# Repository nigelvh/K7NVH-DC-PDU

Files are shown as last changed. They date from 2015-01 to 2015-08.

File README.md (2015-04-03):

K7NVH DC PDU
=======

The K7NVH DC PDU is a device designed to provide remote power control of DC devices in an affordable, low power, and flexible package. Each port is rated to handle 3 amps, and can also measure the current and power flowing through each port.

A variety of features are available, including user defined overcurrent protection, automatic port control based on voltage thresholds, human readable and parseable status displays, port cycling with user defined delay, user defined port state on PDU startup, user defined names for each port and the PDU itself, and options for calibrating the voltage and current sense functions.

Power can be supplied to the device via either USB or a standard barrel jack at 5V, and the device draws approximately 20mA. Please ensure that you supply ONLY regulated 5V. Supplying more than 5V will damage the PDU. You can choose how the device is powered (USB or Barrel Jack) via the solder jumper on the bottom of the board.

The device is available to the host system as a USB serial device, which when accessed accepts a number of basic ASCII commands which can be entered manually, or via a user created script to automate control actions.

This repository contains the source code to be compiled with AVR-GCC, and uploaded to the device via ATMEL's FLIP programmer. There are also resources like CAD files for a case for the device, as well as example resources for configuring a PDU connected computer for providing PDU status data via SNMP.

## Supported Commands
### HELP
The 'HELP' command will print a short message referencing the project page containing documentation.

### STATUS
The 'STATUS' command is designed to give an overview of the running state of each port on the PDU. The port numbers, any configured custom port names, and port state (ENABLED/DISABLED) will be displayed. Input voltage, board temperature, and per port current and power values will be shown. Voltages sensed on the auxiliary inputs will also be displayed. Note that unconnected auxiliary inputs may float and show voltages on unconnected pins. Messages that ports have been disabled due to overload, or are under automatic voltage control are displayed if applicable.

```plain
> STATUS
Voltage: 13.76V Temperature: 25C
PORT 1 "": ENABLED Current: 0.00A Power: 0.0W 
PORT 2 "": ENABLED Current: 0.00A Power: 0.0W 
PORT 3 "": ENABLED Current: 0.00A Power: 0.0W 
PORT 4 "": ENABLED Current: 0.00A Power: 0.0W 
PORT 5 "": ENABLED Current: 0.00A Power: 0.0W 
PORT 6 "": ENABLED Current: 0.00A Power: 0.0W 
PORT 7 "": ENABLED Current: 0.00A Power: 0.0W 
PORT 8 "": ENABLED Current: 0.00A Power: 0.0W 
AUX 1:0.01V 2:0.04V 3:0.01V 4:0.02V 5:0.03V 6:0.00V
```

### PSTATUS
The 'PSTATUS' command is designed to give an overview of the running state of the PDU in a easily parseable format for use with programs querying the PDU for information. The output is in a simple CSV format, defined as follows.

```plain
K7NVH DC PDU,Version Number,Device Name
Input Voltage,Board Temperature
AIN1,AIN2,AIN3,AIN4,AIN5,AIN6
Port Number,Port Name,Binary Enabled/Disabled Flag,Port Current,Port Power,Binary Overload Flag,Automatic Voltage Control Flag
(The above line is repeated for each port)
```
An example output might look like the following.
```plain
> PSTATUS
K7NVH DC PDU,1.1,
2.15,23
0.02,0.04,0.03,0.01,0.01,0.03
0,,1,0.00,0.0,0,0
1,,1,0.00,0.0,0,0
2,,1,0.00,0.0,0,0
3,,1,0.00,0.0,0,0
4,,1,0.00,0.0,0,0
5,,1,0.00,0.0,0,0
6,,1,0.00,0.0,0,0
7,Port 8,1,0.03,0.1,0,0
```

### PON
The 'PON' command is used to enable one or more ports on the PDU.

The PDU supports enabling multiple ports at a time. For example, all of the following are valid 'PON' syntaxes. 'A' can also be substituted for a port number to enable all ports.
`PON 1` `PON 1 2 3 4` `PON A`

### POFF
The 'POFF' command is used to disable one or more ports on the PDU.

The PDU supports disabling multiple ports at a time. For example, all of the following are valid 'POFF' syntaxes. 'A' can also be substituted for a port number to disable all ports.
`POFF 1` `POFF 1 2 3 4` `POFF A`

### PCYCLE
The 'PCYCLE' command is used to disable one or more ports on the PDU for a period of time set by the 'SETCYCLE' command, after which, the port is enabled again.

If 'PCYCLE' is issued on a port that is already disabled, the port will remain disabled for the period of time set by the 'SETCYCLE' command, and will be enabled with any other ports specified.

The PDU supports cycling multiple ports at a time. 'A' can also be substituted for a port number to cycle all ports. The following are valid PCYCLE syntaxes. `PCYCLE 1` `PCYCLE 1 2 3 4` `PCYCLE A`

### SETCYCLE
The 'SETCYCLE' command is used to set the period of time in seconds that ports will be disabled on the PDU during a 'PCYCLE' command. This command has no immediate impact on any ports.

Valid range for the 'SETCYCLE' command is 0-30 seconds. 0 seconds being no delay between disabling and re-enabling a port, and 30 seconds being the maximum delay allowable.

For example, to set a 5 second delay, the following is valid 'SETCYCLE' syntax. `SETCYCLE 5`

### SETDEFON
The 'SETDEFON' command is used to store the desired default state of a given port at PDU boot time to enabled. The PDU will default to all ports being enabled at boot, but you may leave ports disabled at boot with the 'SETDEFOFF' command, or set them back to enabled via 'SETDEFON'.

The PDU supports setting multiple ports at a time to be enabled by default. 'A' can also be substituted for a port number to change all ports. `SETDEFON 1` `SETDEFON 1 2 3 4` `SETDEFON A`

### SETDEFOFF
The 'SETDEFOFF' command is used to store the desired default state of a given port at PDU boot time to disabled. The PDU will default to all ports being enabled at boot, but you may leave ports disabled at boot with the 'SETDEFOFF' command, or set them back to enabled via 'SETDEFON'.

The PDU supports setting multiple ports at a time to be disabled by default. 'A' can also be substituted for a port number to change all ports. `SETDEFOFF 1` `SETDEFOFF 1 2 3 4` `SETDEFOFF A`

### SETNAME
The 'SETNAME' command is used to store a user defined "helpful" name for each port on the PDU. By default the custom names are blank, but they may be set to a user defined string of up to 15 characters in length. Strings longer than 15 characters will be truncated.

The user defined name will be displayed alongside the port number in the output from the 'STATUS' command.

The PDU supports setting only one port name at a time. The following is an example of valid 'SETNAME' syntax, setting Port 1's name to "Testing". `SETNAME 1 Testing`

The 'SETNAME' command can also be used to give the PDU device an overall name by using 'P' in place of the port number. The device name will be displayed as part of the input prompt as a visual aid to ensure users are interacting with the intended device. The following is an example of valid 'SETNAME' syntax to set the device name. `SETNAME P PDU-Test`

The same string length limits that apply to individual port names also apply to the device name.

### SETLIMIT
The 'SETLIMIT' command is used to store a user defined overload current limit for each port on the PDU. By default the current limit is set to 10 amps. While the PDU is not rated for this current flow, 10A was chosen to effectively "disable" current limits from disabling PDU ports.

During normal operation the PDU will continuously check current flow on each port, and compare against the stored limits. If a port is found to exceed the stored limit for greater than 10ms (milliseconds), the port will be disabled, a warning message will be printed, and a overload flag will be displayed in the 'STATUS' output.

If a port has been disabled due to current overload, the port can be re-enabled with a manual 'PON' command.

'SETLIMIT' is set in units of mA (milliamps), and accepts values from 0 to 10000 (0 to 10 amps). However, the provided input will be truncated to tenths of amps. For example, a value of 1150, will be truncated to 1.1A.

The PDU supports setting only one port limit at a time. The following is an example of setting Port 1's current limit to 1.5A. `SETLIMIT 1 1500`

### VCTLON
The 'VCTLON' command is used to enable the PDU to control a given port automatically based on the sensed input voltage. This setting is persistent across reboots of the PDU device. Automatic voltage control of a given port is disabled until manually enabled again, or the PDU is rebooted, in the case of any manual action controlling a port, or an overload condition disables a port.

The voltage thresholds for enabling and disabling a port are set with the 'SETVCTLON' and 'SETVCTLOFF' commands.

Input voltage is polled approximately every 5 seconds, and ports will be enabled/disabled after two consecutive polling cycles have shown voltages beyond the configured thresholds.

Automatic voltage control can be very helpful for battery powered environments, to disable devices if available battery power runs too low. As each port can have unique settings, the user can configure staggered shutdown or startup for equipment as batteries are drained, and subsequently recharged.

The PDU supports setting multiple ports at a time for automatic control. The following are examples of valid syntax for enabling automatic control. `VCTLON 1` `VCTLON 1 2 3 4`

### VCTLOFF
The 'VCTLOFF' command is used to disable the PDU from controlling a given port automatically based on the sensed input voltage. This setting is persistent across reboots of the PDU device.

The PDU supports setting multiple ports at a time for disabled automatic control. The following are examples of valid syntax for disabling automatic control. `VCTLOFF 1` `VCTLOFF 1 2 3 4`

### SETVCTLON
The 'SETVCTLON' command is used to set the voltage, at which a port should be enabled, when configured for automatic control. By default this value is set at 40 volts, the limit of the PDU device, effectively disabling automatic port control.

'SETVCTLON' is set in units of hundredths of volts, and accepts values from 0 to 4000 (0 to 40 volts).

The PDU supports setting only one port enable threshold at a time. The following is an example of setting the enable threshold of Port 1 to 10 volts. `SETVCTLON 1 1000`

### SETVCTLOFF
The 'SETVCTLOFF' command is used to set the voltage, at which a port should be disabled, when configured for automatic control. By default this value is set at 0 volts, effectively disabling automatic port control.

'SETVCTLOFF' is set in units of hundredths of volts, and accepts values from 0 to 4000 (0 to 40 volts).

The PDU supports setting only one port disable threshold at a time. The following is an example of setting the disable threshold of Port 1 to 10 volts. `SETVCTLON 1 1000`

### SETVREF
The 'SETVREF' command is used only during calibration of the PDU. Measuring the voltage reference regulator with an accurate voltage meter, the calibration of voltage and current measurements can be updated.

'SETVREF' is set in units of mV (millivolts), and accepts values from 4000 to 4400 (4.0V to 4.4V). The default value if uncalibrated is the regulator's nominal output voltage of 4.2V.

For example, to set the voltage reference calibration to 4.2V, the following are valid 'SETVREF' syntaxes. `SETVREF4200` `SETVREF 4200`

### SETVCAL
The 'SETVCAL' command is used only during calibration of the PDU. Measuring the voltage divider on the input port with an accurate voltage meter, calibration of voltage supply measurements can be made.

'SETVCAL' is a unitless multiplier, specified in VALUE*10, and accepts values from 150 to 70 (15.0X to 7.0X). The default value if uncalibrated is the dividers's nominal voltage division of 11.0X.

For example, to set the divider reference calibration to 11.0X, the following are valid 'SETVCAL' syntaxes. `SETVCAL110` `SETVCAL 110`

### SETICAL
The 'SETICAL' command is used only during calibration of the PDU. Measuring the voltage divider on the current sense op amp for a given port with an accurate meter, calibration of current sense measurements can be made.

'SETICAL' is a unitless multiplier, specified in VALUE*10, and accepts values from 160 to 60 (16.0X to 6.0X). The default value if uncalibrated is the dividers's nominal voltage division of 11.0X.

For example, to set the calibration on port 1 to 11.0X, the following is valid 'SETICAL' syntax. `SETICAL 1 110`

### DEBUG
The 'DEBUG' command is useful for debugging PDU state. It will output a variety of values, and may not be formatted for easy understanding.

In the cases of unset or default values, the 'DEBUG' command may return a number of unprintable characters to your terminal. This is expected behavior.

## Drivers
The PDU board is automatically recognized as a USB serial device under OSX and Linux, however, windows requires a driver to associate the device with the built in USB serial device drivers.

When first attaching the device to a windows based host, windows will attempt to find a driver and fail. You may then specify a driver. This is provided in K7NVH_PDU.inf.

Once you have installed the driver, the PDU will register as a COM port device under windows, and you may access it with any serial/terminal application of your preference.

### Windows 8 Users
During the driver installation process on Windows 8 operating systems you may encounter *"The third-party INF does not contain digital signature information"* preventing the installation of the included PDU driver.  The steps below outline the process for disabling driver signature enforcement on Windows 8/8.1 systems.

**NOTE:** If your system uses BitLocker Drive Encryption, you will need your encryption key to gain access to advanced settings to disable driver signature enforcement.

Windows 8 - Navigate to PC settings > General and look for the *Advanced startup* dialog.  Click the **Restart now** button to access the advanced startup settings.  Your system will now reboot.

Windows 8.1 - Navigate to PC settings > Update and Recovery > Recovery and look for the *Advanced startup* dialog.  Click the **Restart now** button to access the advanced startup settings.  Your system will now reboot.

After rebooting select Troubleshoot > Advanced options > Startup Settings, click the **Restart** button, your machine will reboot a second time.

After rebooting a second time you should be presented with the Windows Startup Settings dialog, choose *Disable driver signature enforcement* by pressing number `7` on your keyboard.  Your machine will reboot automatically.

Once rebooted, you should now be able to install the PDU drviers as outlined above.  Once the appropriate driver is selected you will see a Windows Security dialog warning against the installation of the unsigned driver.  Click **Install this driver software anyway** to complete the driver installation.

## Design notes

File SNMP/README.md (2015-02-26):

SNMP
=======

## k7nvh_dc_pdu.c
This is the C source for a program to interact with the PDU, and output the data to stdout. Invocation will be along the lines of `k7nvh_dc_pdu /dev/serialDeviceName 'STATUS'` to send the PDU the STATUS command, and print the output. To connect to the PDU, the user running the application must be a member of the 'dialout' group under linux. Under other systems, whatever permissions needed to interact with serial ports are required.

Note that this utility at present simply responds with all output received before a 1 second timeout. This should accomodate all functions except PCYCLE.

## pdu_snmp
This is a PHP script intended to be run on the command line (php-cli is required), and interprets the output from a STATUS command into SNMP OIDs. By default it will read this output from the `/tmp/pdu_status.txt` file. In my environment, this file is populated by an entry in the system crontab, that runs the `k7nvh_dc_pdu` utility. This crontab entry looks like: 
`* * * * *       root    /nigel_scripts/PDU/k7nvh_dc_pdu /dev/ttyACM1 'STATUS' |egrep -i "Voltage|PORT" > /tmp/pdu_status.txt`

Then your snmpd installation needs to be configured to pass the proper OID requests to the `pdu_snmp` script. In my `/etc/snmp/snmpd.conf` file, I have added the following config option:
`pass .1.3.6.1.4.1.8072.2.2048   "/nigel_scripts/PDU/pdu_snmp"`

Now, you should be able to snmpget or snmpwalk PDU data. For example, this will snmpwalk the current usage on each port.
```plain
snmpwalk -v 2c -c <COMMUNITY> <IP ADDRESS> .1.3.6.1.4.1.8072.2.2048.1.3.3
iso.3.6.1.4.1.8072.2.2048.1.3.3.1.1 = STRING: "0.00"
iso.3.6.1.4.1.8072.2.2048.1.3.3.2.1 = STRING: "0.00"
iso.3.6.1.4.1.8072.2.2048.1.3.3.3.1 = STRING: "0.00"
iso.3.6.1.4.1.8072.2.2048.1.3.3.4.1 = STRING: "0.00"
iso.3.6.1.4.1.8072.2.2048.1.3.3.5.1 = STRING: "0.17"
iso.3.6.1.4.1.8072.2.2048.1.3.3.6.1 = STRING: "0.22"
iso.3.6.1.4.1.8072.2.2048.1.3.3.7.1 = STRING: "0.00"
```

Other OIDs of interest that can be walked are:
```plain
.1.3.6.1.4.1.8072.2.2048.1.2.1.1.1 -> Input Voltage
.1.3.6.1.4.1.8072.2.2048.1.3.0 -> Port Index
.1.3.6.1.4.1.8072.2.2048.1.3.1 -> Port Names
.1.3.6.1.4.1.8072.2.2048.1.3.2 -> Port Status
.1.3.6.1.4.1.8072.2.2048.1.3.3 -> Port Current
.1.3.6.1.4.1.8072.2.2048.1.3.4 -> Port Power
```

Please note that SNMP is dumb (IMO) and when interacting with programs like Cacti that expect data to be formatted and organized in a certain way, when adding new data to the OID tree, I may have to reorganize, and thus I do not guarantee the OIDs will remain the same with any updates to this script. Sorry!

## Cacti
The Cacti folder contains some example configuration/templates for Cacti to use to create graphs based on the SNMP data available through the above scripts from the PDU. These work for me and have been exported from my working config, but may not work for you. Please take them as references/examples.

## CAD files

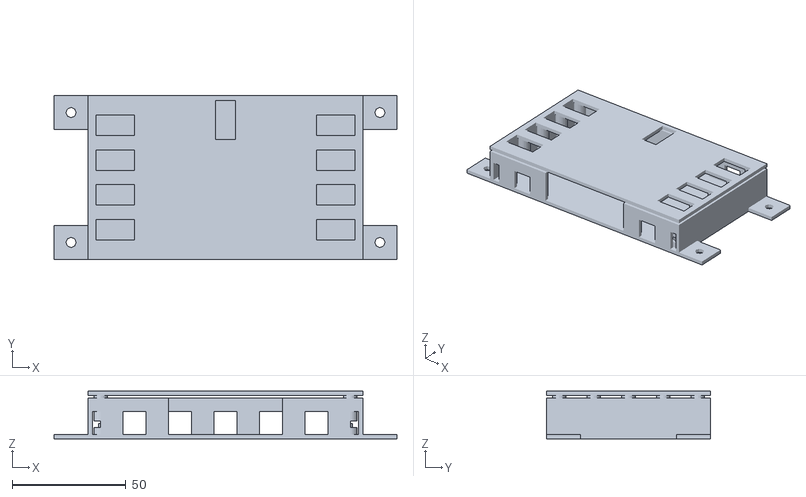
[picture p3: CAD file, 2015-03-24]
Case/K7NVH PDU Case Assembled.stl
150.8 x 72.1 x 21.0

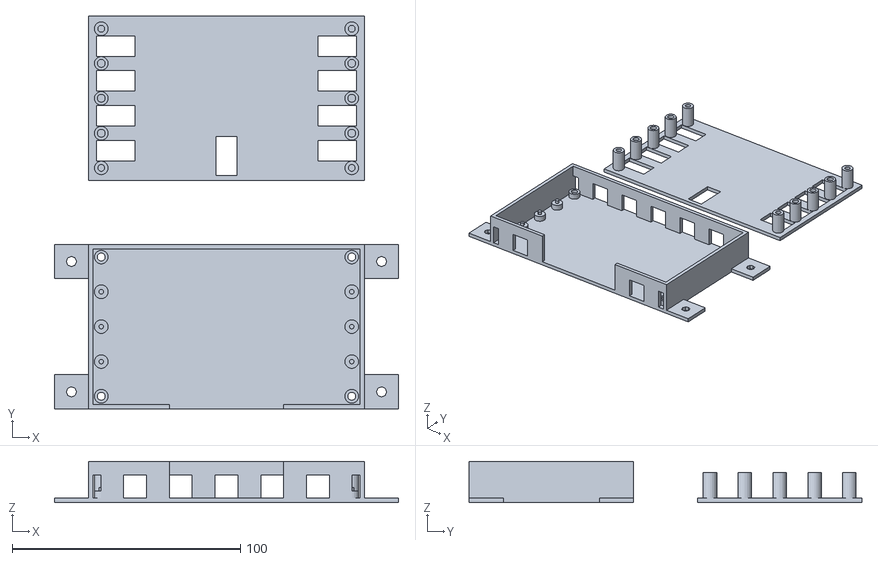
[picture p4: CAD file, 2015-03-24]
Case/K7NVH PDU Case.stl
150.8 x 172.1 x 18.0

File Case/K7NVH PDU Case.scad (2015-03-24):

board_x = 115;
board_y = 66.1;
board_z = 14;
board_thickness = 1.8;

board_spacing = 2;

hole_diameter = 3.5;
screw_hole_diameter = 3;
screw_head_diameter = 8;
post_diameter = 6;
post_base_height = 3;
pin_height = 1.7;
pin_diameter = 2;

wall_thickness = 2;

tab_width = 15;
tab_length = 15;
tab_hole_diameter = 4.5;

peg1_x = -54.85;
peg1_y = 30.48;
peg2_x = -54.85;
peg2_y = -30.48;

peg3_x = 54.85;
peg3_y = 30.48;
peg4_x = 54.85;
peg4_y = -30.48;

peg5_x = -54.85;
peg5_y = 15.3;
peg6_x = 54.85;
peg6_y = 15.3;
peg7_x = -54.85;
peg7_y = -15.3;
peg8_x = 54.85;
peg8_y = -15.3;
peg9_x = -54.85;
peg9_y = 0;
peg10_x = 54.85;
peg10_y = 0;

air_hole_width = 10;
air_hole_height = 10;
air_hole_gap = 10;

powerpole_hole_width = 17;
powerpole_hole_height = 9;
powerpole_input_x = 0;
powerpole_input_y = 25.25;
powerpole_p1_x = 48.5;
powerpole_p1_y = 22.9;
powerpole_p2_x = 48.5;
powerpole_p2_y = 7.6;
powerpole_p3_x = 48.5;
powerpole_p3_y = -7.6;
powerpole_p4_x = 48.5;
powerpole_p4_y = -22.9;
powerpole_p5_x = -48.5;
powerpole_p5_y = 22.9;
powerpole_p6_x = -48.5;
powerpole_p6_y = 7.6;
powerpole_p7_x = -48.5;
powerpole_p7_y = -7.6;
powerpole_p8_x = -48.5;
powerpole_p8_y = -22.9;

// Bottom Plate
difference(){
	cube([board_x + board_spacing + wall_thickness*2, board_y + board_spacing + wall_thickness*2, wall_thickness], center=true);

	// Screw holes and countersinks
	translate([peg1_x, peg1_y, -(wall_thickness/2)]){
		cylinder(h = post_base_height+wall_thickness, r = hole_diameter/2, $fn=20);
		cylinder(h = wall_thickness, r1 = screw_head_diameter/2, r2 = hole_diameter/2, $fn=20);
	}
	translate([peg2_x, peg2_y, -(wall_thickness/2)]){
		cylinder(h = post_base_height+wall_thickness, r = hole_diameter/2, $fn=20);
		cylinder(h = wall_thickness, r1 = screw_head_diameter/2, r2 = hole_diameter/2, $fn=20);
	}
	translate([peg3_x, peg3_y, -(wall_thickness/2)]){
		cylinder(h = post_base_height+wall_thickness, r = hole_diameter/2, $fn=20);
		cylinder(h = wall_thickness, r1 = screw_head_diameter/2, r2 = hole_diameter/2, $fn=20);
	}
	translate([peg4_x, peg4_y, -(wall_thickness/2)]){
		cylinder(h = post_base_height+wall_thickness, r = hole_diameter/2, $fn=20);
		cylinder(h = wall_thickness, r1 = screw_head_diameter/2, r2 = hole_diameter/2, $fn=20);
	}
}

// Mounting Tabs
translate([(board_x + board_spacing + wall_thickness*2)/2 - 0.1 + tab_length/2,(board_y + board_spacing + wall_thickness*2)/2 - tab_width/2,0]){
	difference(){
		#cube([tab_length,tab_width,wall_thickness], center=true);
		cylinder(h = wall_thickness, r = tab_hole_diameter/2, center=true);
	}
}
translate([(board_x + board_spacing + wall_thickness*2)/2 - 0.1 + tab_length/2,-((board_y + board_spacing + wall_thickness*2)/2 - tab_width/2),0]){
	difference(){
		#cube([tab_length,tab_width,wall_thickness], center=true);
		cylinder(h = wall_thickness, r = tab_hole_diameter/2, center=true);
	}
}
translate([-((board_x + board_spacing + wall_thickness*2)/2 - 0.1 + tab_length/2),(board_y + board_spacing + wall_thickness*2)/2 - tab_width/2,0]){
	difference(){
		#cube([tab_length,tab_width,wall_thickness], center=true);
		cylinder(h = wall_thickness, r = tab_hole_diameter/2, center=true);
	}
}
translate([-((board_x + board_spacing + wall_thickness*2)/2 - 0.1 + tab_length/2),-((board_y + board_spacing + wall_thickness*2)/2 - tab_width/2),0]){
	difference(){
		#cube([tab_length,tab_width,wall_thickness], center=true);
		cylinder(h = wall_thickness, r = tab_hole_diameter/2, center=true);
	}
}

// Peg 1
translate([peg1_x, peg1_y, wall_thickness/2]){
	difference(){
		cylinder(h = post_base_height, r = post_diameter/2, $fn=20);
		cylinder(h = post_base_height+wall_thickness, r = hole_diameter/2, $fn=20);
	}
}
// Peg 2
translate([peg2_x, peg2_y, wall_thickness/2]){
	difference(){
		cylinder(h = post_base_height, r = post_diameter/2, $fn=20);
		cylinder(h = post_base_height+wall_thickness, r = hole_diameter/2, $fn=20);
	}
}
// Peg 3
translate([peg3_x, peg3_y, wall_thickness/2]){
	difference(){
		cylinder(h = post_base_height, r = post_diameter/2, $fn=20);
		cylinder(h = post_base_height+wall_thickness, r = hole_diameter/2, $fn=20);
	}
}
// Peg 4
translate([peg4_x, peg4_y, wall_thickness/2]){
	difference(){
		cylinder(h = post_base_height, r = post_diameter/2, $fn=20);
		cylinder(h = post_base_height+wall_thickness, r = hole_diameter/2, $fn=20);
	}
}

// Peg 5
translate([peg5_x, peg5_y, wall_thickness/2]){
	cylinder(h = post_base_height, r = post_diameter/2, $fn=20);
	translate([0,0,post_base_height]){
		cylinder(h = pin_height, r = pin_diameter/2, $fn=20);
	}
}
// Peg 6
translate([peg6_x, peg6_y, wall_thickness/2]){
	cylinder(h = post_base_height, r = post_diameter/2, $fn=20);
	translate([0,0,post_base_height]){
		cylinder(h = pin_height, r = pin_diameter/2, $fn=20);
	}
}
// Peg 7
translate([peg7_x, peg7_y, wall_thickness/2]){
	cylinder(h = post_base_height, r = post_diameter/2, $fn=20);
	translate([0,0,post_base_height]){
		cylinder(h = pin_height, r = pin_diameter/2, $fn=20);
	}
}
// Peg 8
translate([peg8_x, peg8_y, wall_thickness/2]){
	cylinder(h = post_base_height, r = post_diameter/2, $fn=20);
	translate([0,0,post_base_height]){
		cylinder(h = pin_height, r = pin_diameter/2, $fn=20);
	}
}
// Peg 9
translate([peg9_x, peg9_y, wall_thickness/2]){
	cylinder(h = post_base_height, r = post_diameter/2, $fn=20);
	translate([0,0,post_base_height]){
		cylinder(h = pin_height, r = pin_diameter/2, $fn=20);
	}
}
// Peg 10
translate([peg10_x, peg10_y, wall_thickness/2]){
	cylinder(h = post_base_height, r = post_diameter/2, $fn=20);
	translate([0,0,post_base_height]){
		cylinder(h = pin_height, r = pin_diameter/2, $fn=20);
	}
}

// -X Wall
translate([-(board_x + board_spacing + wall_thickness)/2,0,(board_z + wall_thickness)/2 + wall_thickness/2]){
	cube([wall_thickness, board_y + board_spacing + wall_thickness*2, board_z + wall_thickness], center=true);
}
// +X Wall
translate([(board_x + board_spacing + wall_thickness)/2,0,(board_z + wall_thickness)/2 + wall_thickness/2]){
	cube([wall_thickness, board_y + board_spacing + wall_thickness*2, board_z + wall_thickness], center=true);
}
// -Y Wall
difference(){
	translate([0,-(board_y + board_spacing + wall_thickness)/2,(board_z + wall_thickness)/2 + wall_thickness/2]){
		cube([(board_x + board_spacing + wall_thickness*2), wall_thickness, board_z + wall_thickness], center=true);
	}
	translate([0,0,wall_thickness/2 + air_hole_height*2/2]){
		#cube([air_hole_width*5, (board_y + board_spacing + wall_thickness*2), air_hole_height*2], center=true);
	}
	translate([(air_hole_width+air_hole_gap)*2,0,wall_thickness/2 + air_hole_height/2]){
		#cube([air_hole_width, (board_y + board_spacing + wall_thickness*2), air_hole_height], center=true);
	}
	translate([(air_hole_width+air_hole_gap)*3,0,wall_thickness/2 + air_hole_height/2]){
		#cube([air_hole_width, (board_y + board_spacing + wall_thickness*2), air_hole_height], center=true);
	}
	translate([-(air_hole_width+air_hole_gap)*2,0,wall_thickness/2 + air_hole_height/2]){
		#cube([air_hole_width, (board_y + board_spacing + wall_thickness*2), air_hole_height], center=true);
	}
	translate([-(air_hole_width+air_hole_gap)*3,0,wall_thickness/2 + air_hole_height/2]){
		#cube([air_hole_width, (board_y + board_spacing + wall_thickness*2), air_hole_height], center=true);
	}
}
// +Y Wall
difference(){
	translate([0,(board_y + board_spacing + wall_thickness)/2,(board_z + wall_thickness)/2 + wall_thickness/2]){
		cube([(board_x + board_spacing + wall_thickness*2), wall_thickness, board_z + wall_thickness], center=true);
	}
	translate([0,0,wall_thickness/2 + air_hole_height/2]){
		#cube([air_hole_width, (board_y + board_spacing + wall_thickness*2), air_hole_height], center=true);
	}
	translate([(air_hole_width+air_hole_gap)*1,0,wall_thickness/2 + air_hole_height/2]){
		#cube([air_hole_width, (board_y + board_spacing + wall_thickness*2), air_hole_height], center=true);
	}
	translate([(air_hole_width+air_hole_gap)*2,0,wall_thickness/2 + air_hole_height/2]){
		#cube([air_hole_width, (board_y + board_spacing + wall_thickness*2), air_hole_height], center=true);
	}
	translate([(air_hole_width+air_hole_gap)*3,0,wall_thickness/2 + air_hole_height/2]){
		#cube([air_hole_width, (board_y + board_spacing + wall_thickness*2), air_hole_height], center=true);
	}
	translate([-(air_hole_width+air_hole_gap)*1,0,wall_thickness/2 + air_hole_height/2]){
		#cube([air_hole_width, (board_y + board_spacing + wall_thickness*2), air_hole_height], center=true);
	}
	translate([-(air_hole_width+air_hole_gap)*2,0,wall_thickness/2 + air_hole_height/2]){
		#cube([air_hole_width, (board_y + board_spacing + wall_thickness*2), air_hole_height], center=true);
	}
	translate([-(air_hole_width+air_hole_gap)*3,0,wall_thickness/2 + air_hole_height/2]){
		#cube([air_hole_width, (board_y + board_spacing + wall_thickness*2), air_hole_height], center=true);
	}
}
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

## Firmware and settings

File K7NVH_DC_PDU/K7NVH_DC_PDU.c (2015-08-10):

/* (c) 2015 Nigel Vander Houwen */
//
// TODO
// High water mark stored in EEPROM (Lifetime & User resettable)
// Port locking?
// Watchdog - Problem exists where reset dumps into DFU, and waits there.
// Up/down arrow keys?

#include "K7NVH_DC_PDU.h"

ISR(WDT_vect){
	timer++;
	
	if ((timer) % VCTL_DELAY == 0){ check_voltage = 1; }
	if ((timer) % ICTL_DELAY == 0){ check_current = 1; }
}

// Main program entry point.
int main(void) {
	// Initialize some variables
	int16_t BYTE_IN = -1;
	
	// Set the watchdog timer to interrupt for timekeeping
	MCUSR &= ~(1 << WDRF);
	WDTCSR |= 0b00011000; // Set WDCE and WDE to enable WDT changes
	WDTCSR = 0b01000011; // Enable watchdog interrupt and Interrupt at 0.25s

	// Save some power by disabling peripherals.
	PRR0 &= 0b11010111;
	PRR1 &= 0b11111110;
	ACSR &= 0b10111111;
	ACSR |= 0b10001000;

	// Divide 16MHz crystal down to 1MHz for CPU clock.
	clock_prescale_set(clock_div_16);

	// Init USB hardware and create a regular character stream for the
	// USB interface so that it can be used with the stdio.h functions
	USB_Init();
	CDC_Device_CreateStream(&VirtualSerial_CDC_Interface, &USBSerialStream);

	// Enable interrupts
	GlobalInterruptEnable();

	run_lufa();

	// Wait 5 seconds so that we can open a console to catch startup messages
	for (uint16_t i = 0; i < 500; i++) {
		_delay_ms(10);
	}

	// Print startup message
	printPGMStr(PSTR(SOFTWARE_STR));
	fprintf(&USBSerialStream, " V%s,%s", HARDWARE_VERS, SOFTWARE_VERS);
	run_lufa();

	// Start up SPI
	SPI_begin();

	// Set up control pins
	DDRB |= (1 << P1EN)|(1 << P2EN)|(1 << P3EN)|(1 << P4EN);
	DDRC |= (1 << P5EN)|(1 << P6EN)|(1 << P7EN)|(1 << P8EN);
	DDRD |= (1 << LED1)|(1 << LED2);

	// Read in stored port on/off states, and turn them on/off to match
	for (uint8_t i = 0; i < PORT_CNT; i++) {
		PORT_BOOT_STATE[i] = EEPROM_Read_Port_Boot_State(i);
		if (PORT_BOOT_STATE[i] & 0b00000001) { PORT_CTL(i, 1); } else { PORT_CTL(i, 0); } // Enable port if set
		if (PORT_BOOT_STATE[i] & 0b00000010) { PORT_STATE[i] |= 0b00000100; } // Enable VCTL if set
	}
	run_lufa();

	INPUT_Clear();

// ~~~~~~~~~~~~~~~~~~~~~~~~~~~~~~~~~~~~~~~~~~~~
// ~~ Main system loop
// ~~~~~~~~~~~~~~~~~~~~~~~~~~~~~~~~~~~~~~~~~~~~

	for (;;) {
		// Read a byte from the USB serial stream
		BYTE_IN = CDC_Device_ReceiveByte(&VirtualSerial_CDC_Interface);

		// USB Serial stream will return <0 if no bytes are available.
		if (BYTE_IN >= 0) {
			// We've gotten a char, so lets blink the green LED onboard. This LED will 
			// remain lit while the board is processing commands. This is most evident 
			// during a PCYCLE.
			LED_CTL(0, 1);
			
			// Echo the char we just received back out the serial stream so the user's 
			// console will display it.
			fputc(BYTE_IN, &USBSerialStream);

			// Switch on the input byte to determine what is is and what to do.
			switch (BYTE_IN) {
				case 8:
				case 127:
					// Handle Backspace chars.
					if (DATA_IN_POS > 0){
						DATA_IN_POS--;
						DATA_IN[DATA_IN_POS] = 0;
						printPGMStr(STR_Backspace);
					}
					break;

				case '\n':
				case '\r':
					// Newline, Parse our command
					INPUT_Parse();
					INPUT_Clear();
					break;

				case 3:
					// Ctrl-c bail out on partial command
					INPUT_Clear();
					break;
				
				case 29:
					// Ctrl-] reset all eeprom values
					EEPROM_Reset();
					INPUT_Clear();
					break;
					
				case 30:
					// Ctrl-^ jump into the bootloader
					TIMSK0 = 0b00000000; // Interrupt will mess with the bootloader
					bootloader();
					break; // We should never get here...

				default:
					// Normal char buffering
					if (DATA_IN_POS < (DATA_BUFF_LEN - 1)) {
						DATA_IN[DATA_IN_POS] = BYTE_IN;
						DATA_IN_POS++;
						DATA_IN[DATA_IN_POS] = 0;
					} else {
						// Input is too long.
						printPGMStr(STR_Unrecognized);
						INPUT_Clear();
					}
					break;
			}
		}

		// Turn the green LED back off again
		LED_CTL(0, 0);
		
		// Check for above threshold current usage
		if (check_current) {
			Check_Current_Limits();
			check_current = 0;
		}
		
		// Timer interval, check voltage control
		if (check_voltage) {
			Check_Voltage_Cutoff();
			check_voltage = 0;
		}
		
		// Keep the LUFA USB stuff fed regularly.
		run_lufa();
	}
}

// ~~~~~~~~~~~~~~~~~~~~~~~~~~~~~~~~~~~~~~~~~~~~
// ~~ Command Parsing Functions
// ~~~~~~~~~~~~~~~~~~~~~~~~~~~~~~~~~~~~~~~~~~~~

// Flush out our data input buffer, reset our position variable, and print a new prompt.
static inline void INPUT_Clear(void) {
	memset(&DATA_IN[0], 0, sizeof(DATA_IN));
	DATA_IN_POS = 0;
	
	// Read PDU name
	char temp_name[16];
	EEPROM_Read_Port_Name(-1, temp_name);
	
#ifdef ENABLECOLORS
	fprintf(&USBSerialStream, "\r\n\r\n#\x1b[32m%s \x1b[36m>\x1b[0m ", temp_name);
#else
	fprintf(&USBSerialStream, "\r\n\r\n#%s > ", temp_name);
#endif
}

// Parse command arguments and return pd_set bitmap with relevant port
// bits set.
static inline void INPUT_Parse_args(pd_set *pd, char *str) {
	*pd = 0;

	while (*str != 0 && str < (DATA_IN + DATA_BUFF_LEN)) {
		if (*str >= '1' && *str <= '8') {
			*pd = *pd | (1 << (*str - '1'));
		} else if (*str == 'A' || *str == 'a') {
			*pd = 0b11111111;
		}
		str++;
	}
}

// We've gotten a new command, parse out what they want.
static inline void INPUT_Parse(void) {
	pd_set pd; // Port descriptor bitmap

	// HELP - Print a basic help menu
	if (strncasecmp_P(DATA_IN, STR_Command_HELP, 4) == 0) {
		PRINT_Help();
		return;
	}
	// STATUS - Print a port status summary for all ports
	if (strncasecmp_P(DATA_IN, STR_Command_STATUS, 6) == 0) {
		PRINT_Status();
		return;
	}
	// PSTATUS - Print a status summary in a parser friendly output
	if (strncasecmp_P(DATA_IN, STR_Command_PSTATUS, 7) == 0) {
		PRINT_Status_Prog();
		return;
	}
	// DEBUG - Print a report of debugging information, including EEPROM variables
	if (strncasecmp_P(DATA_IN, STR_Command_DEBUG, 10) == 0) {
		DEBUG_Dump();
		return;
	}
	// PON - Turn on a port or list of ports
	if (strncasecmp_P(DATA_IN, STR_Command_PON, 3) == 0) {
		INPUT_Parse_args(&pd, DATA_IN + 3);
		PORT_Set_Ctl(&pd, 1);
		return;
	}
	// POFF - Turn off a port or a list of ports
	if (strncasecmp_P(DATA_IN, STR_Command_POFF, 4) == 0) {
		INPUT_Parse_args(&pd, DATA_IN + 4);
		PORT_Set_Ctl(&pd, 0);
		return;
	}
	// PCYCLE - Power cycle a port or list of ports. Time is defined by EEPROM_Read_PCycle_Time().
	if (strncasecmp_P(DATA_IN, STR_Command_PCYCLE, 6) == 0) {
		INPUT_Parse_args(&pd, DATA_IN + 6);
		
		PORT_Set_Ctl(&pd, 0);

		fprintf(&USBSerialStream, "\r\n");
		run_lufa();
		for (uint16_t i = 0; i < (EEPROM_Read_PCycle_Time()); i++) {
			_delay_ms(1000);
			fputc('.', &USBSerialStream);
			run_lufa();
		}

		PORT_Set_Ctl(&pd, 1);
		
		return;
	}
	// SETCYCLE - Set PCYCLE_TIME and store in EEPROM
	if (strncasecmp_P(DATA_IN, STR_Command_SETCYCLE, 8) == 0) {
		uint16_t temp_set_time = atoi(DATA_IN + 8);
		if (temp_set_time <= PCYCLE_MAX_TIME) {
			printPGMStr(STR_PCYCLE_Time);
			fprintf(&USBSerialStream, "%i", temp_set_time);
			EEPROM_Write_PCycle_Time((uint8_t)temp_set_time);
			return;
		}
	}
	// SETDEF - Set the port default state
	if (strncasecmp_P(DATA_IN, STR_Command_SETDEF, 6) == 0) {
		char *str = DATA_IN + 6;
		uint8_t state = 255;
		if (strncasecmp_P(str, PSTR("ON"), 2) == 0) {
			state = 1;
		}
		if (strncasecmp_P(str, PSTR("OFF"), 3) == 0) {
			state = 0;
		}
		if (state <= 1) {
			INPUT_Parse_args(&pd, (state ? DATA_IN+8 : DATA_IN+9));
			for (uint8_t i = 0; i < PORT_CNT; i++) {
				if (pd & (1 << i)) {
					if (state == 1) {
						PORT_BOOT_STATE[i] |= 0b00000001;
					}else{
						PORT_BOOT_STATE[i] &= 0b11111110;
					}
					EEPROM_Write_Port_Boot_State(i, PORT_BOOT_STATE[i]);
				
					printPGMStr(STR_Port_Default);
					fprintf(&USBSerialStream, "%i ", i+1);
					printPGMStr(state ? STR_Enabled : STR_Disabled);
				}
			}
			return;
		}
	}
	// VCTL - Enable/Disable Voltage Control
	if (strncasecmp_P(DATA_IN, STR_Command_VCTL, 4) == 0) {
		char *str = DATA_IN + 4;
		uint8_t setting = 255;
		if (strncasecmp_P(str, PSTR("ON"), 2) == 0) {
			setting = 1;
		}
		if (strncasecmp_P(str, PSTR("OFF"), 3) == 0) {
			setting = 0;
		}
		if (setting <= 1) {
			INPUT_Parse_args(&pd, (setting ? DATA_IN+6 : DATA_IN+7));
			for (uint8_t i = 0; i < PORT_CNT; i++) {
				if (pd & (1 << i)) {
					if (setting == 1) {
						PORT_BOOT_STATE[i] |= 0b00000010;
						PORT_STATE[i] |= 0b00000100;
					}else{
						PORT_BOOT_STATE[i] &= 0b11111101;
						PORT_STATE[i] &= 0b11111011;
					}
					EEPROM_Write_Port_Boot_State(i, PORT_BOOT_STATE[i]);
					
					fprintf(&USBSerialStream, "\r\n");
					printPGMStr(STR_Command_VCTL);
					fprintf(&USBSerialStream, " %i ", i+1);
					printPGMStr(setting ? STR_Enabled : STR_Disabled);
				}
			}
			return;
		}
	}
	// SETVCTL - Set ON/OFF Voltages for Voltage Control
	if (strncasecmp_P(DATA_IN, STR_Command_SETVCTL, 7) == 0) {
		char *str = DATA_IN + 7;
		int8_t portid;
		uint8_t setting = 255;
		if (strncasecmp_P(str, PSTR("ON"), 2) == 0) {
			setting = 1;
			str += 2;
		}
		if (strncasecmp_P(str, PSTR("OFF"), 3) == 0) {
			setting = 0;
			str += 3;
		}
		if (setting <= 1) {
			while (*str == ' ' || *str == '\t') str++;
			if (*str >= '1' && *str <= '8') {
				portid = *str - '1';
				str++;
				
				uint16_t temp_set_voltage = atoi(str);
				if ((float)(temp_set_voltage/100) <= VMAX){
					if (setting == 1) {
						EEPROM_Write_Port_CutOn(portid, temp_set_voltage);
					} else {
						EEPROM_Write_Port_CutOff(portid, temp_set_voltage);
					}
					printPGMStr(STR_Port_VCTL);
					fprintf(&USBSerialStream, "%.2fV", (float)temp_set_voltage/100);
					return;
				}
			}
		}
		// EEPROM_Write_Port_CutOff(uint8_t port, uint16_t cutoff)
		// EEPROM_Write_Port_CutOn(uint8_t port, uint16_t cuton)
	}
	// SETNAME - Set the name for a given port.
	if (strncasecmp_P(DATA_IN, STR_Command_SETNAME, 7) == 0) {
		char *str = DATA_IN + 7;
		int8_t portid;
		char temp_name[16];

		while (*str == ' ' || *str == '\t') str++;
		if (*str >= '1' && *str <= '8') {
			portid = *str - '1';
			
			str++;
			while (*str == ' ' || *str == '\t') str++;

			EEPROM_Write_Port_Name(portid, str);
			
			printPGMStr(STR_NR_Port);
			EEPROM_Read_Port_Name(portid, temp_name);
			fprintf(&USBSerialStream, "%i NAME: %s", portid + 1, temp_name);
			return;
		} else if (*str == 'P') {
			portid = -1;
			
			str++;
			while (*str == ' ' || *str == '\t') str++;

			EEPROM_Write_Port_Name(portid, str);
			return;
		}
	}
	// SETLIMIT - Set the current limit for a given port.
	if (strncasecmp_P(DATA_IN, STR_Command_SETLIMIT, 8) == 0) {
		char *str = DATA_IN + 8;
		uint8_t portid;
		
		while (*str == ' ' || *str == '\t') str++;
		if (*str >= '1' && *str <= '8') {
			portid = *str - '1';
			str++;
		
			uint16_t temp_set_limit = (atoi(str) / 100);
			if (temp_set_limit <= LIMIT_MAX){
				EEPROM_Write_Port_Limit(portid, temp_set_limit);
				printPGMStr(STR_Port_Limit);
				fprintf(&USBSerialStream, "%.1fA", (float)temp_set_limit/10);
				return;
			}
		}
	}
	// SETVREF - Set the VREF voltage and store in EEPROM to correct voltage readings.
	if (strncasecmp_P(DATA_IN, STR_Command_SETVREF, 7) == 0) {
		uint16_t temp_set_vref = atoi(DATA_IN + 7);
		if (temp_set_vref >= VREF_MIN && temp_set_vref <= VREF_MAX){
			float temp_vref = (float)temp_set_vref / 1000.0;
			EEPROM_Write_REF_V(temp_vref);
			printPGMStr(STR_VREF);
			fprintf(&USBSerialStream, "%.3fV", temp_vref);
			return;
		}
	}
	// SETVCAL - Set the VCAL and store in EEPROM to correct voltage readings.
	if (strncasecmp_P(DATA_IN, STR_Command_SETVCAL, 7) == 0) {
		uint16_t temp_set_vdiv = atoi(DATA_IN + 7);
		if (temp_set_vdiv >= VCAL_MIN && temp_set_vdiv <= VCAL_MAX){
			float temp_vdiv = (float)temp_set_vdiv / 10.0;
			EEPROM_Write_V_CAL(temp_vdiv);
			printPGMStr(STR_VCAL);
			fprintf(&USBSerialStream, "%.1f", temp_vdiv);
			return;
		}
	}
	// SETICAL - Set the current calibration for a given port and store in EEPROM to 
	// correct current readings.
	if (strncasecmp_P(DATA_IN, STR_Command_SETICAL, 7) == 0) {
		char *str = DATA_IN + 7;
		uint8_t portid;
		
		while (*str == ' ' || *str == '\t') str++;
		if (*str >= '1' && *str <= '8') {
			portid = *str - '1';
			str++;
		
			uint16_t temp_i_cal = atoi(str);
			if (temp_i_cal >= ICAL_MIN && temp_i_cal <= ICAL_MAX){
				EEPROM_Write_I_CAL(portid, (float)(temp_i_cal / 10.0));
				printPGMStr(STR_ICAL);
				fprintf(&USBSerialStream, "%.1f", (float)(temp_i_cal / 10.0));
				return;
			}
		}
	}
	
	// If none of the above commands were recognized, print a generic error.
	printPGMStr(STR_Unrecognized);
}

// ~~~~~~~~~~~~~~~~~~~~~~~~~~~~~~~~~~~~~~~~~~~~
// ~~ Printing Functions
// ~~~~~~~~~~~~~~~~~~~~~~~~~~~~~~~~~~~~~~~~~~~~

// Print a summary of all ports status'
static inline void PRINT_Status(void) {
	float voltage, current;
	
	// Voltage
	voltage = ADC_Read_Input_Voltage();
	printPGMStr(PSTR("\r\nVoltage: "));
	fprintf(&USBSerialStream, "%.2fV", voltage);
	
	// Temperature
	printPGMStr(PSTR("\tTemperature: "));
	fprintf(&USBSerialStream, "%.0fC", ADC_Read_Temperature());
	
	// Ports
	for(uint8_t i = 0; i < PORT_CNT; i++) {
		// PORT
		printPGMStr(STR_NR_Port);
		
		// Number and Name
		char temp_name[16];
		EEPROM_Read_Port_Name(i, temp_name);
		fprintf(&USBSerialStream, "%i \"%s\": ", i+1, temp_name);
		
		// Enabled/Disabled
		if (PORT_STATE[i] & 0b00000001) { printPGMStr(STR_Enabled); } else { printPGMStr(STR_Disabled); }
		
		// Current reading
		current = ADC_Read_Port_Current(i);
		printPGMStr(PSTR(" Current: "));
		fprintf(&USBSerialStream, "%.2fA ", current);
		// Power reading
		printPGMStr(PSTR("Power: "));
		fprintf(&USBSerialStream, "%.1fW", (voltage * current));
		
		// Overload?
		if (PORT_STATE[i] & 0b00000010) { printPGMStr(STR_Overload); }
		
		// Voltage Control?
		if (PORT_STATE[i] & 0b00000100) { printPGMStr(STR_VCTL); }
	}
	
	// Aux Inputs
	printPGMStr(PSTR("\r\nAUX "));
	for (uint8_t j = 0; j < 6; j++) {
		fprintf(&USBSerialStream, "%i:%.2fV ", j+1, ADC_Read_Raw_Voltage(j, 1));
	}
}

// Print programmatical status output
static inline void PRINT_Status_Prog(void){
	char temp_name[16];
	float voltage = ADC_Read_Input_Voltage();
	
	// Device Description,Software version,Unit Name
	EEPROM_Read_Port_Name(-1, temp_name); //PDU Name
	printPGMStr(PSTR(SOFTWARE_STR));
	fprintf(&USBSerialStream, ",%s,%s", SOFTWARE_VERS, temp_name);
	
	// Input Voltage,Temperature
	fprintf(&USBSerialStream, "\r\n%.2f,%.0f", voltage, ADC_Read_Temperature());
	
	// AIN1,AIN2,AIN3,AIN4,AIN5,AIN6
	fprintf(&USBSerialStream, "\r\n%.2f,%.2f,%.2f,%.2f,%.2f,%.2f", ADC_Read_Raw_Voltage(0, 1), \
		ADC_Read_Raw_Voltage(1, 1), ADC_Read_Raw_Voltage(2, 1), ADC_Read_Raw_Voltage(3, 1), \
		ADC_Read_Raw_Voltage(4, 1), ADC_Read_Raw_Voltage(5, 1));
	
	// Port Number,Port Name,Enabled?,Current,Power,Overload
	for (uint8_t i = 0; i < PORT_CNT; i++) {
		EEPROM_Read_Port_Name(i, temp_name);
		
		uint8_t port_state = (PORT_STATE[i] & 0b00000001);
		uint8_t port_overload = (PORT_STATE[i] & 0b00000010) >> 1;
		uint8_t port_vctl = (PORT_STATE[i] & 0b00000100) >> 2;
		
		float current = ADC_Read_Port_Current(i);
		float power = current * voltage;
		
		fprintf(&USBSerialStream, "\r\n%i,%s,%i,%.2f,%.1f,%i,%i", i+1, temp_name, port_state, \
			current, power, port_overload, port_vctl);
	}
}

// Print a quick help command
static inline void PRINT_Help(void) {
	printPGMStr(STR_Help_Info);
}

// Print a PGM stored string
static inline void printPGMStr(PGM_P s) {
	char c;
	while((c = pgm_read_byte(s++)) != 0) fputc(c, &USBSerialStream);
}

// ~~~~~~~~~~~~~~~~~~~~~~~~~~~~~~~~~~~~~~~~~~~~
// ~~ Port/LED Control Functions
// ~~~~~~~~~~~~~~~~~~~~~~~~~~~~~~~~~~~~~~~~~~~~

// Set all ports in a port descriptor set to a state
static inline void PORT_Set_Ctl(pd_set *pd, uint8_t state) {
	for (uint8_t i = 0; i < PORT_CNT; i++) {
		if (*pd & (1 << i)) {
			PORT_CTL(i, state);
			
			// If a port is controlled manually, make sure that voltage control gets disabled
			// Does not disable voltage control settings stored in EEPROM
			PORT_STATE[i] &= 0b11111011;
		}
	}
}

// Turn a port ON (state == 1) or OFF (state == 0)
static inline void PORT_CTL(uint8_t port, uint8_t state) {
	printPGMStr(STR_NR_Port);
	fprintf(&USBSerialStream, "%i ", port+1);

	if (state == 1) {
		if (port <= 3) {
			PORTB |= (1 << (4 + port));
		} else if (port <= 7) {
			PORTC |= (1 << (11 - port));
		}
		printPGMStr(STR_Enabled);
		PORT_STATE[port] |= 0b00000001;
	} else {
		if (port <= 3) {
			PORTB &= ~(1 << (4 + port));
		} else if (port <= 7) {
			PORTC &= ~(1 << (11 - port));
		}
		printPGMStr(STR_Disabled);
		PORT_STATE[port] &= 0b11111110;
	}
	
	// Clear any overload marks since we're manually setting this port
	PORT_STATE[port] &= 0b11111101;
}

// Turn a LED ON (state == 1) or OFF (state == 0)
// LED 0 == Green, LED 1 == Red
static inline void LED_CTL(uint8_t led, uint8_t state) {
	if (state == 1) {
		PORTD |= (1 << (LED1 + led));
	} else {
		PORTD &= ~(1 << (LED1 + led));
	}
}

// Check all ports for exceeding current limits, disable the port, and set the RED led.
static inline void Check_Current_Limits(void){
	// Check for above threshold current usage
	for (uint8_t i = 0; i < 8; i++) {
		if (PORT_Check_Current_Limit(i)) {
			// Current is above threshold. Print a warning message.
			fprintf(&USBSerialStream, "\r\n");
			printPGMStr(STR_Overload);
				
			// Disable the port
			PORT_CTL(i, 0);
			
			// Mark the overload bit for this port
			PORT_STATE[i] |= 0b00000010;
				
			// If a port overloads, make sure that voltage control gets disabled
			// Does not disable voltage control settings stored in EEPROM
			PORT_STATE[i] &= 0b11111011;
				
			// Turn the RED LED on.
			LED_CTL(1, 1);
				
			INPUT_Clear();
		}
	}
		
	// If no ports are listed as overload anymore, disable the RED led.
	uint8_t error = 0;
	for (uint8_t i = 0; i < PORT_CNT; i++) {
		if ((PORT_STATE[i] & 0x02) > 0) error++;
	}
	if (error == 0) LED_CTL(1, 0);
}

// Checks a port against the stored current limit. Returns 0 if below limits, and 1 if
// the port has exceeded current limits.
static inline uint8_t PORT_Check_Current_Limit(uint8_t port){
	// Check for above threshold current flow, and return 1.
	if (ADC_Read_Port_Current(port) > ((float)EEPROM_Read_Port_Limit(port) / 10.0)) { return 1; }
	
	// Else return 0;
	return 0;
}

// Checks the disable voltage setting for each port and disables the port if it has fallen 
// below the cutoff threshold, and re-enables if it is above the cuton threshold.
static inline void Check_Voltage_Cutoff(void){
	float voltage = ADC_Read_Input_Voltage();
	
	for (uint8_t i = 0; i < PORT_CNT; i++) {
		if ((PORT_STATE[i] & 0b00000100) > 0) {
			// 
			if ((voltage < EEPROM_Read_Port_CutOff(i) && (PORT_STATE[i] & 0b00000001)) || (voltage > EEPROM_Read_Port_CutOn(i) && !(PORT_STATE[i] & 0b00000001))) {
				// Check if this is the second time through, if so, disable the port.
				// If it's the first time through, set the VCTL changing bit
				if ((PORT_STATE[i] & 0b00001000) > 0) {
					// If it's below the cutoff, turn the port off
					// If it's above the cuton, turn the port on
					if (voltage < EEPROM_Read_Port_CutOff(i)) {
						// Disable the port
						PORT_CTL(i, 0);
					}
					if (voltage > EEPROM_Read_Port_CutOn(i)) {
						// Enable the port
						PORT_CTL(i, 1);
					}
					
					// Clear the VCTL changing bit
					PORT_STATE[i] &= 0b11110111;
					
					INPUT_Clear();
				} else {
					PORT_STATE[i] |= 0b00001000;
				}
			// If voltage is above thresholds, reset any VCTL changing bit that was applied.
			} else {
				// Clear the VCTL changing bit
				PORT_STATE[i] &= 0b11110111;
			}
		}
	}
}

// ~~~~~~~~~~~~~~~~~~~~~~~~~~~~~~~~~~~~~~~~~~~~
// ~~ EEPROM Functions
// ~~~~~~~~~~~~~~~~~~~~~~~~~~~~~~~~~~~~~~~~~~~~ 

// Read the default port state setting
static inline uint8_t EEPROM_Read_Port_Boot_State(uint8_t port) {
	uint8_t state = eeprom_read_byte((uint8_t*)(EEPROM_OFFSET_PORT_DEFAULTS + port));
	if (state == 255) state = 1;
	return state;
}
// Write the default port state setting
static inline void EEPROM_Write_Port_Boot_State(uint8_t port, uint8_t state) {
	eeprom_update_byte((uint8_t*)(EEPROM_OFFSET_PORT_DEFAULTS + port), state);
}

// Read the stored reference voltage from EEPROM
static inline float EEPROM_Read_REF_V(void) {
	float REF_V = eeprom_read_float((float*)(EEPROM_OFFSET_REF_V));
	// If the value seems out of range (uninitialized), default it to 4.5
	if (REF_V < 4.3 || REF_V > 4.7 || isnan(REF_V)) REF_V = 4.5;
	return REF_V;
}
// Write the reference voltage to EEPROM
static inline void EEPROM_Write_REF_V(float reference) {
	eeprom_update_float((float*)(EEPROM_OFFSET_REF_V), reference);
}

// Read the stored reference voltage from EEPROM
static inline float EEPROM_Read_V_CAL(void) {
	uint8_t V_CAL = eeprom_read_byte((uint8_t*)(EEPROM_OFFSET_V_CAL));
	// If the value seems out of range (uninitialized), default it to 11
	if (V_CAL < VCAL_MIN || V_CAL > VCAL_MAX) V_CAL = 110;
	return (float)(V_CAL / 10.0);
}
// Write the reference voltage to EEPROM
static inline void EEPROM_Write_V_CAL(float div) {
	eeprom_update_byte((uint8_t*)(EEPROM_OFFSET_V_CAL), (int)(div * 10.0));
}

// Read the stored port current calibration
static inline float EEPROM_Read_I_CAL(uint8_t port) {
	uint8_t I_CAL = eeprom_read_byte((uint8_t*)(EEPROM_OFFSET_I_CAL + port));
	if(I_CAL < ICAL_MIN || I_CAL > ICAL_MAX) I_CAL = 110;
	return (float)(I_CAL / 10.0);
}
// Write the port current calibration to EEPROM
static inline void EEPROM_Write_I_CAL(uint8_t port, float cal) {
	eeprom_update_byte((uint8_t*)(EEPROM_OFFSET_I_CAL + port), (int)(cal * 10.0));
}

// Read PCYCLE_TIME from EEPROM
// Stored as Seconds
static inline uint8_t EEPROM_Read_PCycle_Time(void) {
	uint8_t PCYCLE_TIME = eeprom_read_byte((uint8_t*)(EEPROM_OFFSET_CYCLE_TIME));
	if (PCYCLE_TIME > PCYCLE_MAX_TIME) PCYCLE_TIME = 1;
	return PCYCLE_TIME;
}
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

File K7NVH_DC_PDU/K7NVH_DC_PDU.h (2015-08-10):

/* (c) 2015 Nigel Vander Houwen */
#ifndef _K7NVH_DC_PDU_H_
#define _K7NVH_DC_PDU_H_

// ~~~~~~~~~~~~~~~~~~~~~~~~~~~~~~~~~~~~~~~~~~~~
// ~~ Includes
// ~~~~~~~~~~~~~~~~~~~~~~~~~~~~~~~~~~~~~~~~~~~~

#include <avr/io.h>
#include <avr/wdt.h>
#include <avr/power.h>
#include <avr/sleep.h>
#include <avr/interrupt.h>
#include <util/delay.h>
#include <string.h>
#include <stdio.h>
#include <stdlib.h>
#include <avr/pgmspace.h>
#include <avr/eeprom.h>

#include <LUFA/Drivers/USB/USB.h>
#include <LUFA/Platform/Platform.h>

#include "Descriptors.h"

// ~~~~~~~~~~~~~~~~~~~~~~~~~~~~~~~~~~~~~~~~~~~~
// ~~ Macros
// ~~~~~~~~~~~~~~~~~~~~~~~~~~~~~~~~~~~~~~~~~~~~

// Enable ANSI color codes to be sent. Uses a small bit of extra program space for 
// storage of color codes/modified strings.
#define ENABLECOLORS

#define SOFTWARE_STR "\r\nK7NVH DC PDU"
#define HARDWARE_VERS "1.1"
#define SOFTWARE_VERS "1.1"
#define PORT_CNT    8
#define INPUT_CNT	8
#define DATA_BUFF_LEN    32
#define ADC_AVG_POINTS   5

#define SPI_CLOCK_DIV4 0x00
#define SPI_CLOCK_DIV16 0x01
#define SPI_CLOCK_DIV64 0x02
#define SPI_CLOCK_DIV128 0x03
#define SPI_CLOCK_DIV2 0x04
#define SPI_CLOCK_DIV8 0x05
#define SPI_CLOCK_DIV32 0x06

#define SPI_MODE0 0x00
#define SPI_MODE1 0x04
#define SPI_MODE2 0x08
#define SPI_MODE3 0x0C

#define SPI_MODE_MASK 0x0C  // CPOL = bit 3, CPHA = bit 2 on SPCR
#define SPI_CLOCK_MASK 0x03  // SPR1 = bit 1, SPR0 = bit 0 on SPCR
#define SPI_2XCLOCK_MASK 0x01  // SPI2X = bit 0 on SPSR

// SPI pins
#define SPI_SS_PORTS PB0
#define SPI_SS_INPUTS PD6
#define SPI_SCK PB1
#define SPI_MOSI PB2
#define SPI_MISO PB3

// Output port controls
#define P1EN PB4
#define P2EN PB5
#define P3EN PB6
#define P4EN PB7
#define P5EN PC7
#define P6EN PC6
#define P7EN PC5
#define P8EN PC4

// LED1 = Green, LED2 = Red
#define LED1 PD0
#define LED2 PD1

// Limits
#define PCYCLE_MAX_TIME 30 // Seconds
#define VREF_MAX 4700 // 4.7V * 1000
#define VREF_MIN 4300 // 4.3V * 1000
#define VCAL_MAX 150 // 15.0
#define VCAL_MIN 70 // 7.0
#define LIMIT_MAX 100 // Stored as amps*10 so 50==5.0A
#define ICAL_MAX 160 // 160/10 = 16.0
#define ICAL_MIN 60 // 60/10 = 6.0
#define VMAX 40

// Timing
#define VCTL_DELAY 20 // Ticks. ~5s
#define ICTL_DELAY 1 // Ticks. ~0.25s

// EEPROM Offsets
#define EEPROM_OFFSET_PORT_DEFAULTS 0 // 8 bytes at offset 0
#define EEPROM_OFFSET_REF_V 8 // 4 bytes at offset 8
#define EEPROM_OFFSET_V_CAL 12 // 1 bytes at offset 12
#define EEPROM_OFFSET_CYCLE_TIME 13 // 1 byte at offset 13
// 14-15
#define EEPROM_OFFSET_LIMIT 16 // 8 Bytes at offset 16
#define EEPROM_OFFSET_I_CAL 24 // 8 Bytes at offset 24
// 32-47
#define EEPROM_OFFSET_PDUNAME 48 // 16 bytes at offset 48
#define EEPROM_OFFSET_P0NAME 64 // 16 bytes at offset 64
#define EEPROM_OFFSET_P1NAME 80 // 16 bytes at offset 80
#define EEPROM_OFFSET_P2NAME 96 // 16 bytes at offset 96
#define EEPROM_OFFSET_P3NAME 112 // 16 bytes at offset 112
#define EEPROM_OFFSET_P4NAME 128 // 16 bytes at offset 128
#define EEPROM_OFFSET_P5NAME 144 // 16 bytes at offset 144
#define EEPROM_OFFSET_P6NAME 160 // 16 bytes at offset 160
#define EEPROM_OFFSET_P7NAME 176 // 16 bytes at offset 176
#define EEPROM_OFFSET_V_CUTOFF 192 // 16 Bytes at offset 192
#define EEPROM_OFFSET_V_CUTON 208 // 16 Bytes at offset 208

// ~~~~~~~~~~~~~~~~~~~~~~~~~~~~~~~~~~~~~~~~~~~~
// ~~ Globals
// ~~~~~~~~~~~~~~~~~~~~~~~~~~~~~~~~~~~~~~~~~~~~

// Timer
volatile unsigned long timer = 0;
// Schedule
volatile uint8_t check_voltage = 0;
volatile uint8_t check_current = 0;

typedef uint8_t pd_set; // Port Descriptor Set - bitmap of ports

// Port State Set - bitmap of port state
// (NUL,NUL,NUL,NUL,VCTL Changing,VCTL Enabled?,Overload,Enabled?)
typedef uint8_t ps_set;
// Port Boot State Set - bitmap of port boot state
// (NUL,NUL,NUL,NUL,NUL,NUL,VCTL Enabled?,Enabled?)
typedef uint8_t pbs_set;

// Standard file stream for the CDC interface when set up, so that the
// virtual CDC COM port can be used like any regular character stream
// in the C APIs.
static FILE USBSerialStream;

// Help string
const char STR_Help_Info[] PROGMEM = "\r\nVisit https://github.com/nigelvh/K7NVH-DC-PDU for full docs.";

// Reused strings
#ifdef ENABLECOLORS
//	const char STR_Color_Red[] PROGMEM = "\x1b[31m";
//	const char STR_Color_Green[] PROGMEM = "\x1b[32m";
//	const char STR_Color_Blue[] PROGMEM = "\x1b[34m";
//	const char STR_Color_Cyan[] PROGMEM = "\x1b[36m";
//	const char STR_Color_Reset[] PROGMEM = "\x1b[0m";
	const char STR_Unrecognized[] PROGMEM = "\r\n\x1b[31mINVALID COMMAND\x1b[0m";
	const char STR_Enabled[] PROGMEM = "\x1b[32mENABLED\x1b[0m";
	const char STR_Disabled[] PROGMEM = "\x1b[31mDISABLED\x1b[0m";
	const char STR_Overload[] PROGMEM = " \x1b[31m!OVERLOAD!\x1b[0m";
	const char STR_VCTL[] PROGMEM = " \x1b[36mVOLTAGE CTL\x1b[0m";
#else
	const char STR_Unrecognized[] PROGMEM = "\r\nINVALID COMMAND";
	const char STR_Enabled[] PROGMEM = "ENABLED";
	const char STR_Disabled[] PROGMEM = "DISABLED";
	const char STR_Overload[] PROGMEM = " !OVERLOAD!";
	const char STR_VCTL[] PROGMEM = " VOLTAGE CTL";
#endif	

const char STR_Backspace[] PROGMEM = "\x1b[D \x1b[D";
const char STR_NR_Port[] PROGMEM = "\r\nPORT ";
const char STR_Port_Default[] PROGMEM = "\r\nPORT DEFAULT ";
const char STR_PCYCLE_Time[] PROGMEM = "\r\nPCYCLE TIME: ";
const char STR_Port_Limit[] PROGMEM = "\r\nPORT LIMIT: ";
const char STR_Port_CutOff[] PROGMEM = "\r\nPORT CUTOFF: ";
const char STR_Port_CutOn[] PROGMEM = "\r\nPORT CUTON: ";
const char STR_Port_VCTL[] PROGMEM = "\r\nPORT VCTL: ";
const char STR_VREF[] PROGMEM = "\r\nVREF: ";
const char STR_VCAL[] PROGMEM = "\r\nVCAL: ";
const char STR_ICAL[] PROGMEM = "\r\nICAL: ";

// Command strings
const char STR_Command_HELP[] PROGMEM = "HELP";
const char STR_Command_STATUS[] PROGMEM = "STATUS";
const char STR_Command_PSTATUS[] PROGMEM = "PSTATUS";
const char STR_Command_DEBUG[] PROGMEM = "DEBUG";
const char STR_Command_PON[] PROGMEM = "PON";
const char STR_Command_POFF[] PROGMEM = "POFF";
const char STR_Command_PCYCLE[] PROGMEM = "PCYCLE";
const char STR_Command_SETCYCLE[] PROGMEM = "SETCYCLE";
const char STR_Command_SETDEF[] PROGMEM = "SETDEF";
const char STR_Command_SETVREF[] PROGMEM = "SETVREF";
const char STR_Command_SETVCAL[] PROGMEM = "SETVCAL";
const char STR_Command_SETICAL[] PROGMEM = "SETICAL";
const char STR_Command_SETNAME[] PROGMEM = "SETNAME";
const char STR_Command_SETLIMIT[] PROGMEM = "SETLIMIT";
const char STR_Command_VCTL[] PROGMEM = "VCTL";
const char STR_Command_SETVCTL[] PROGMEM = "SETVCTL";

// Port to ADC Address look up table
// PORT 1,2,3,4,5,6,7,8
const uint8_t ADC_Ports[PORT_CNT] = \
		{0b10000000, 0b10010000, 0b10100000, 0b10110000, \
		 0b11000000, 0b11010000, 0b11100000, 0b11110000};
// Input to ADC Address look up table
// EXT1, EXT2, EXT3, EXT4, EXT5, EXT6, INPUT, TEMP
const uint8_t ADC_Inputs[INPUT_CNT] = \
		{0b10000000, 0b10010000, 0b10100000, 0b11010000, \
		 0b11100000, 0b11110000, 0b10110000, 0b11000000};
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

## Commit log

2015-01-26 Initial commit of K7NVH DC PDU project.
    [BoardDeviceMap.cfg, BootloaderDeviceMap.cfg]
2015-01-26 Deleting non existant files.
    [BoardDeviceMap.cfg, BootloaderDeviceMap.cfg]
2015-01-26 Updated PRINT_Status() to use previously defined PGM string.
2015-01-26 Fixed permissions/filename RE a30e8ed566cecb5d1c0cc3e92c03e42b379f2fdd
    [K7NVH_DC_PDU.c]
2015-01-26 Fixed line breaks on USB comment
    [K7NVH_DC_PDU.c]
2015-01-26 Comment fixes and typos re:macros
    [K7NVH_DC_PDU.c]
2015-01-26 Updated copyright statement to reflect current year.
2015-01-27 Fixed setting pd in the case of 'a' or 'A' in INPUT_Parse_args
    [K7NVH_DC_PDU.c]
2015-01-27 Fixed display of proper port number after changes to argument parsing.
    [K7NVH_DC_PDU.c]
2015-01-27 Implemented PCYCLE and SETPCYCLE commands. Cycle time is saved to eeprom, or defaults to 1 second. Max value defined by PCYCLE_MAX_TIME, set to 30s presently. Updated EEPROMDUMP to output PCYCLE stor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
2015-01-27 Finished SETVREF implementation. Example SETVREF4200 for 4.200V. Added unrecognized command message for commands that exceed buffer length.
2015-01-30 Initial work on overload protection. Need to add methods to set current limits, as well as store state that port was disabled due to overload.
2015-02-06 Implemented current limit setting, and stored current limit values to EEPROM.
2015-02-06 Rearranged SETNAME to avoid need to explicit error print. Instead conditional checks for good, and default unrecognized handles bad commands.
    [K7NVH_DC_PDU.c]
2015-02-06 Finished documenting currently available commands. Adjusted SETVREF and SETSENSE commands to allow for whitespace before set value.
2015-02-06 Initial commit of windows driver K7NVH_PDU.inf
2015-02-06 Fixed typos and updated comment in windows driver.
2015-02-06 Updated README.md with documentation regarding installing driver for windows.
2015-02-09 Added SETVDIV calibration option due to a fault with the input voltage divider on one of the beta boards, requiring calibration separate from the nominal 10.1X division factor.
2015-02-14 Added feature to turn on RED LED when overload occurs, and disable it after all port overloads are cleared.
2015-02-17 Added command to jump into the bootloader to avoid the need to physically short the reset line to reprogram.
    [K7NVH_DC_PDU.c, K7NVH_DC_PDU.h]
2015-02-18 Added OpenSCAD case design and STL for a 3D printed case.
    [K7NVH PDU Case.scad, K7NVH PDU Case.stl]
2015-02-23 Update README.md
    Update driver installation notes for Windows 8 users.
2015-02-26 Added initial commit of some example utilities to get SNMP data from the PDU via the host system the PDU is attached to.
2015-03-08 Initial modifications to support hardware V1.1, port and led functions should still work fine. ADC based functions will need work to differentiate based on which ADC a desired resource is attached to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
2015-03-10 Fix reading voltage and temperature.
    [K7NVH_DC_PDU.c, K7NVH_DC_PDU.h]
2015-03-13 Fixed comment for key combo to jump to bootloader
    [K7NVH_DC_PDU.c]
2015-03-13 Added function to set current calibration per port. Adjusted existing voltage sense calibration function to match naming scheme and to reduce EEPROM storage space requirements (4 bytes for float down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
    [K7NVH_DC_PDU.c, K7NVH_DC_PDU.h]
2015-03-13 Added output of AUX input voltages to STATUS command output. Added ADC_Read_Raw_Voltage() to remove duplication of code converting raw ADC counts to voltages referenced to V_REF.
2015-03-13 Updated STATUS printing for aux inputs. Updated readme with STATUS example output.
2015-03-16 Added device name functionality, and updated the related documentation for SETNAME.
2015-03-16 Changed string comparison to be case insensitive for commands.
2015-03-20 Added watchdog interrupt at 0.25s incrementing a counter to provide timekeeping to be used in future updates with regard to voltage control of ports.
2015-03-23 Updated case scad and stl to use thinner walls (cheaper/faster printing), overall height is reduced. Spacing on Powerpole cutouts is adjusted.
    [K7NVH PDU Case Assembled.stl, K7NVH PDU Case.scad]
2015-03-24 Further minor revision to placements/sizing on case.
    [K7NVH PDU Case Assembled.stl, K7NVH PDU Case.scad, K7NVH PDU Case.stl]
2015-03-24 Fundamental work on voltage control completed. Need to add command to allow setting of the thresholds, and implement checking on an interval rather than every loop. Need to update docs when completed.
2015-04-03 Completed implementation of voltage control commands, code, and documentation.
2015-04-04 Fixed bug limiting precision of SETICAL command.
    [K7NVH_DC_PDU.c]
2015-08-10 Added averaging when sampling ADC to reduce noise. Incremented software version number to 1.1. Number of averaging points definied by ADC_AVG_POINTS value. Note that larger values increase the time i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
    [K7NVH_DC_PDU.c, K7NVH_DC_PDU.h]
